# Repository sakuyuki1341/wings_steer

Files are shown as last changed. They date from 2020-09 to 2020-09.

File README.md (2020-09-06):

# wings_steer

"wings_steer" is a system of steering in U.E.C.wings.

# DEMO

No information.(Additional information will come soon.)

# Features

to use Arduino in this system.
Befor we use Renesas, but now we use it to takeover.

# Requirement

No information.(Additional information will come soon.)

# Installation

No information.(Additional information will come soon.)

# Usage

No information.(Additional information will come soon.)

# Note

No informa

# Author

* Sakuyuki
* U.E.C.wings
* y1810678@gmail.com

# License

"wings_steer" is under [MIT license](https://en.wikipedia.org/wiki/MIT_License).

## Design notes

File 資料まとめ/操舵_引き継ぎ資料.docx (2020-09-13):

# 2020 操舵引き継ぎ資料

## 初めに

まず初めに、今回の操舵はワイヤーリンケージではなく、フライ・バイ・ワイヤを用いて作成しています。それを念頭においた上で読んでください。フライ・バイ・ワイヤとはつまりマイコンでサーボモータを制御して、サーボモータで尾翼を駆動する方式のことです。

また、このサーボモータと尾翼の接合方法についてはここでは説明を行えません。理由は筆者がその部分を担当していなかったためです。
ではどうするかですが、その部分は設計に任せてください。サーボモータの仕様を伝えて強度計算が行われたしっかりしたものを作ってもらうと安心です。

## 基本設計について

操舵はアナログスティックを倒すことで、尾翼のサーボモータを駆動させる回路及びプログラムの作成が最終目的となります。

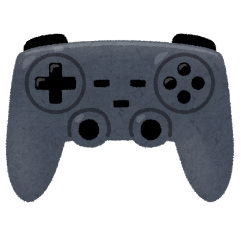
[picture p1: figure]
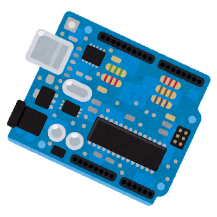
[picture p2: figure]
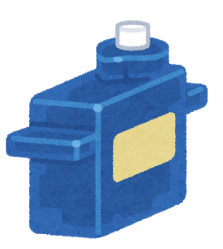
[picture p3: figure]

そこで、必要になるのは「マイコン」「アナログスティック」の３つです。その他に、これらを繋ぎ合わせる基板の設計。マイコンへのプログラミングなどとやらなければいけないことは沢山あります。

## マイコンについて

#### 使用する製品について

使用するマイコンは試用に「Arduino Uno」を。実際に基板に組み込むために「Arduino Nano」を使用します。Nanoは Unoの互換品で機能はそのまま、大きさだけ小さくなったものです。ただ、Nanoは小さく、テストに使用するには不便なため、試し段階であればUnoの使用が推奨されます。

Arduino Nano 販売ページ(秋月電子)(http://akizukidenshi.com/catalog/g/gM-09059/)
Arduino Uno 販売ページ(秋月電子)(http://akizukidenshi.com/catalog/g/gM-07385/)

メーカーは「Arduino Srl」で、上記の製品は秋月電子や千石電商、Amazonなどでも販売されています。また、Amazonでは廉価版、一般にはコピー商品と呼ばれるものが販売されているのでそちらを購入するのも良いでしょう。無論、廉価版でも機能に違いはありません。ただ、保護回路が省略されていたりするので、その点には注意が必要です。

#### 製品の特徴について

- プログラム作成が楽で、プログラム作成のための資料が多くある。
  - Arduino以上に初心者に優しいマイコンは無いため、これを使用している。
  - 入門用の学習書や、学習サイトが豊富なため、自分自身で学べる。

#### 補足

以前はRENESASのマイコンを使用していた。そちらはより軽量でより単価が安く、より高性能となっています。しかしながら使用するには一定以上の高度な技術と知識が必要となるので推奨しません。RENESAS以外にもpicマイコンという安価なマイコンがあるため、使用するにはそちらを選択してください。なぜなら、RENESASに比べてpicは多少資料が多いため、いざとなったらインターネットで検索をすれば使用方法などの知識を得やすいからです。

もし、Arduinoから別のマイコンへと乗り換えるのであれば引継ぎはしっかりと行ってください。

## アナログスティックについて

アナログスティックに関しては、本資料を読むよりも先に該当のデータシートを見ることを強く推奨します。また、本資料にはデータシートには書いていない注意事項を記載しているので、その点については本資料で確認してほしいです。

#### 使用する製品について

使用しているアナログスティックは「SainSmart」の「JoyStick Module」で、秋月電子で販売されています。

JoyStick Module 販売ページ(秋月電子)(http://akizukidenshi.com/catalog/g/gM-08763/)

#### 製品の特徴について

- 中央部と外縁部のデッドゾーンが大きく、繊細な動きをしづらい。

#### 補足

特徴の項目からも分かるように、この使用しているアナログスティックは性能が低いです。そのため、実際に機体に搭載する際はより高機能なアナログスティックを購入、使用する必要があります。また、アナログスティックを変更した場合は、それに応じてマイコン側のプログラムも適宜変更してください。

## サーボモータについて

サーボモータはアナログスティックと異なり、データシートが複雑で読むのが辛いと思うので、ここではできるだけ噛み砕いて書いていきたいと思います。
　ただ、噛み砕くということは細部について触れないということなので、そこについてはデータシートや、公式が配布している資料を読んでください。

#### 使用する製品について

使用するサーボモータは「近藤科学」の「KRS-4031HV ICS」で、通販などで販売されています。(昔はツクモロボット王国という店で店頭販売されてたけど、最近はどこで買えるのかわからないです。申し訳ないです。)

近藤科学 公式販売ページ(https://kondo-robot.com/product/krs-4031hv-ics)

#### 製品の特徴について

- 「ICS3.5」という近藤科学独自のシリアル通信規格での制御が可能なため、信頼性が高い。 無論、pwm制御も対応しており、そちらを利用して制御することもできる。
- 駆動電圧が9-12Vで、リポバッテリーを直付けで駆動できる。
- サーボホーンは付属していないため、この製品に対応したものを購入する必要がある。 例：近藤科学 サーボホーン公式販売ページ(hhttps://kondo-robot.com/product/allowhighthorn)

#### 補足

この他にもサーボモータは様々な企業が販売しているため、一番使いやすいサーボモータを探してみるのも良いでしょう。ただ、その際はトルクや駆動電圧には細心の注意を払う必要があります。また、近藤科学のサーボモータにも色々種類があるので、尾翼の駆動のために更にトルクが必要になった場合などは、トルクの大きいものに買い替えてください。

また、サーボモータを駆動するためのICS3.5という通信規格ですが、当然ではありますが、Arduinoでポンと出力することはできません。そのため、適切な回路設計とソフトウェア設計が必要です。
　一応、公式側からArduino用のライブラリが公開されているのでそれを利用してもいいでしょう。(筆者は参考サイト様：リンク(https://qiita.com/kedtn/items/7174f5112d99f12ce0e7))を見ながら自分で組んだので、どのようにライブラリを利用するのか分からないので解説はできません。)
　他にも公式から、ICS3.5用のモジュールが購入できるみたいです。自分で回路を設計できない場合はそれを利用するのが一番安全です。
　あと、ソフトウェア側の解説でも記述するのですが、Arduinoのソフトウェアシリアル機能は115200bpsに対応していないので、ArduinoでICS3.5を使用するならハードウェアシリアルを使用してください。

## 操舵基板(回路)について

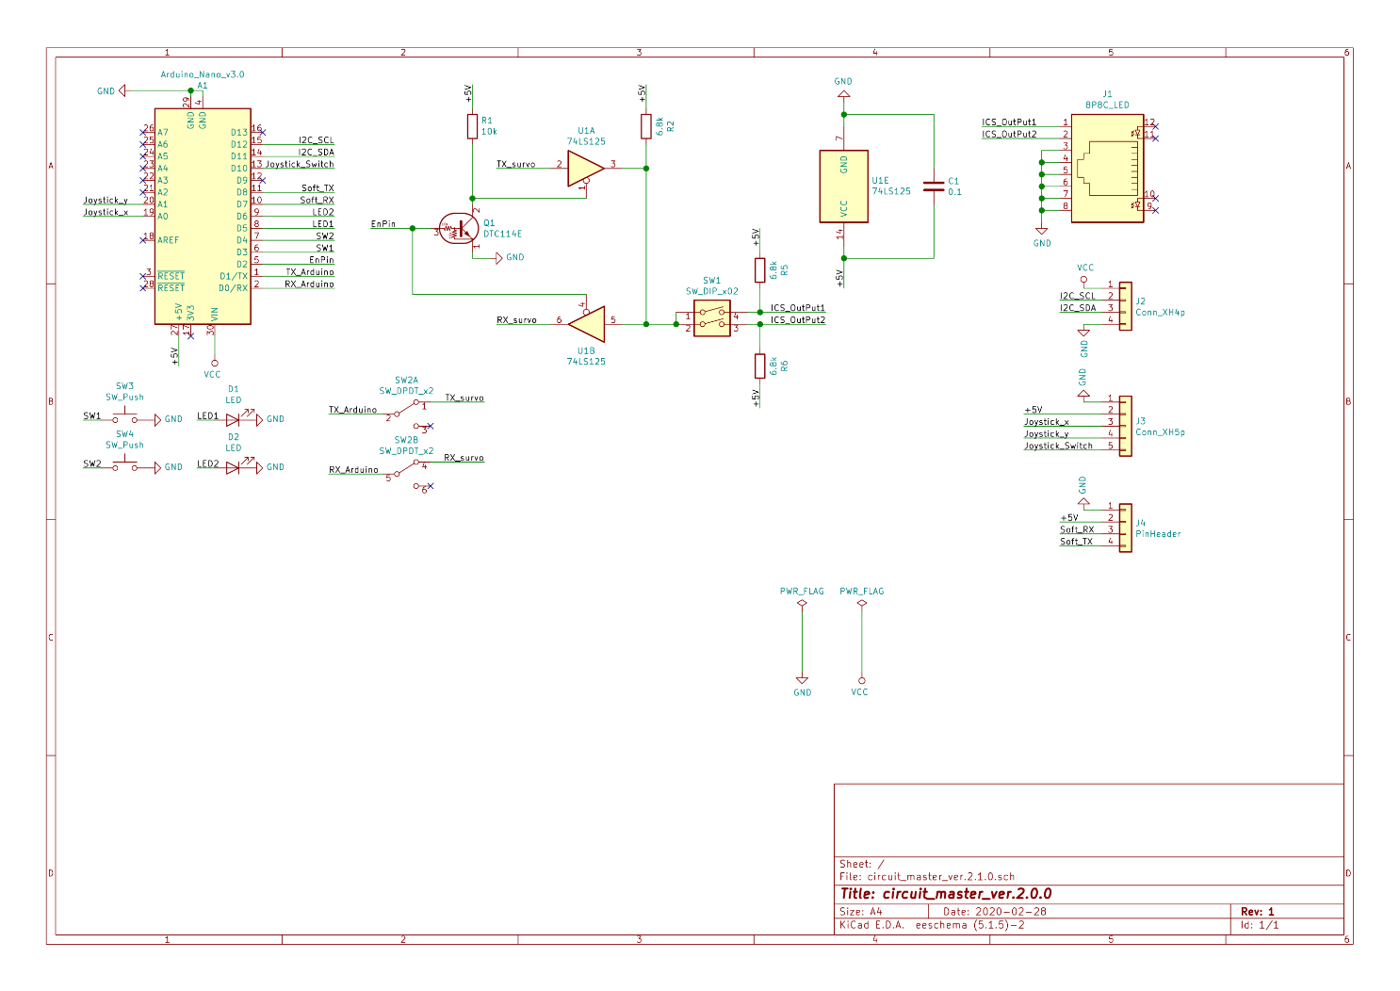
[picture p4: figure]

操舵基板というのは、マイコンとその他の電子部品を詰め込んだ基板のことを指します。下の画像が現在使用している操舵基板の回路図です。

#### 操舵基板の役割について

操舵基板は操舵の電気的部分に関するほぼ全てを担います。そのためこの基板と「メイン基板」「尾翼側にあるサーボモータ」「コックピットのアナログスティック」を接続する必要があります。

また、情報処理もこの基板内で行いたいので、Arduino本体もこの基板に搭載することとなります。

それ以外にも、Arduinoの動作状況を確認するためのLEDや、Arduinoのデバッグを行うためのシリアル通信用のポート、Arduinoを操作するためのスイッチも搭載しています。

#### 設計について

回路図の設計はKiCadを用いて行いました。なので、回路図や基板を見る場合はそれを利用してください。自身で新規に基板や回路を作成する場合は、KiCadを用いても良いですし、Eagleを用いても良いでしょう。

なお、回路の設計には「KiCad Basics」と「自作基板への道」という参考資料を活用しました。この２つは引き継ぎの資料に同梱してあるので活用してください。

#### 回路について

回路図とパーツについては、渡したデータを参照すれば、どれがどれに対応しているか分かるかと思います。

#### 設計時の注意点

- サーボモータはArduinoのハードウェアシリアルで制御する必要があります。そのため、UARTをICS3.5へ変換する回路はハードウェアシリアルの出力のピンへと接続しましょう。
- ICS3.5へ変換する回路を接続したままだと、Arduinoへの書き込みができません。そのため、ここの接続を切るためのスイッチが必要です。上記回路図上だとSW2に該当します。
- ハードウェアシリアルはサーボモータとの通信に専用されます。そのためデバッグ用にソフトウェアシリアルを用いてArduinoと通信するためのピンを用意しましょう。 恐らくですが、Arduino Nanoはソフトウェアシリアルに使用できるピンに制限はないと思われます。D2~D12かに割り当てれば問題ないはずです。
- インジケータ用のLEDと、スイッチは用意しておきましょう。忘れるソフトウェア設計面でも支障がでます。

#### 備考(LANコネクタについて )

今回の基板ではLANコネクタを搭載することにしています。これは操舵基板と尾翼のサーボモータを接続するためのものです。つまり、操舵基板とサーボモータはLANケーブルで接続するということです。

LANケーブルで接続するのは何点かメリットがあります。

1. 接続、切断がアタッチメントを用いることで容易に可能であること。
2. 挿し間違いが極めて発生しづらい。
3. ケーブルの代替品が簡単に用意できる。

もちろん、通常のケーブルと比べて重量の増加というデメリットも発生するので、安定重視ならLANケーブルを。効率重視なら専用ケーブルを選択するのが良いでしょう。

#### 備考(各要素との接続端子について)

アナログスティックと操舵基板間

XH規格の圧着端子をつけた銅線を用いて接続します。その際には「アナログスティック_x軸」「アナログスティック_y軸」「アナログスティック_スイッチ」「5V」「GND」の5ピン必要となるため、対応したものを選びましょう。
　ケーブルは一般的な安価な銅線で問題ないでしょう。

サーボモータと操舵基板間

前述の通り、LANケーブルを用いて接続します。とは言え、LANケーブルとサーボモータを直接繋ぐことはできないので、LANケーブルをピンヘッダへ変換する基板を尾翼周辺に配置して、変換をした後にサーボモータへ接続することとなります。また、その変換基板にサーボモータ用電源も接続し、サーボモータはその変換基板とのみ接続できるようにしました。
　操舵基板からは「GND」「サーボモータ１の通信線」「サーボモータ２の通信線」の3種類。LANピンヘッダ変換基板では、サーボモータそれぞれに「GND」「通信線」「VCC(12V)」の３つ。操舵基板との「GND」「サーボモータの通信線」×２(ただしLANを用いる)。サーボモータ電源(リポバッテリー)との「GND」「VCC(12V)」の２つ(ピンヘッダ)を用意します。

## 操舵基板(基板)について

前項では主に回路について記述しました。本項では基板の設計について書いていきます。基板の設計の画像はレイヤーでごちゃごちゃしているので載せません。KiCadを使って自身で実際に確認してみてください。

#### 設計について

基板の設計ですが、回路の「設計について」の項目と内容は同じのため省略します。

#### 発注について

発注はFusionPCBが恐らく一番安価だと思います。品質も問題ないので活用しましょう。

一応、学内のものつくりセンターに基板作成機がありますが、使用方法が面倒な上、品質もお世辞にも良いとは言えないので、おすすめしません。もしどうしても使用したいならば、事前にものつくりセンターに登録を行い、使用方法を確認しておきましょう。
　使用方法はwikiに記述されているはずです。(なかったら申し訳ないです。)

#### 設計及び発注時の注意点

- 一つ一つの電子素子(トランジスタとか)のデータシートをみて、ピン配置について確認しましょう。稀に予定していたものとズレていることがあります。また、回路図とも照らし合わせて考え通りに割り当てがなされているかを確認しましょう。
- 発注する際は必ず発注先のサイトでガーバーデータの生成方法を確かめましょう。そこに一通り生成方法が記述されているので、生成で手間取ることもなく進められるはずです。
- 誤発注を避けるため、ガーバーデータを提出したら、確認ページを見ましょう。そうすればきっと誤発注が防げる…はず。

## Arduinoに書き込むプログラムについて

この項ではArduinoに書き込むプログラムについて解説します。恐らく長くなるので心して読んでください。なお、基本的なArduinoのプログラミングはこなしたものとして説明を行います。そのため、Arduinoってなんぞやって人は、事前に「Arduino 入門」とかで検索をして、少なくともLEDをボタンで光らせる程度はできるようになっておいてください。

#### ソースコードのダウンロードについて

Arduinoへ書き込むソースコードは筆者のgithub上→(リンク：https://github.com/sakuyuki1341/wings_steer)にあります。また、ソースコードだけでなく、本資料や回路図などなどもあるので確認してみてください。

本番用のプログラムは「master」というディレクトリに入っているので、そこから最新のバージョンをダウンロードしてください。

#### 概要

このプログラムは6つのファイルがあります。それぞれ以下のような役割を持ちます。

1. steering_master_ver.1.0.ino：setup関数やloop関数の存在するメイン部。
2. servo_ver.1.0.ino：サーボモータの駆動に関する関数群
3. analog_stick_ver.1.0.ino：アナログスティックに関する関数群
4. command_line_ver.1.0.ino：コマンドラインに関する関数群
5. memory_ver.1.0.ino：メモリの読み書きに関する関数群
6. subs_ver.1.0.h ：構造体や変数、関数の宣言をまとめたもの。

これらそれぞれについて順に解説をしていきます。

#### subs_ver.1.0.hについて

このファイルでは、他のファイルが使う変数、定数、関数、構造体の宣言を行っています。

#### Steering_master_ver.1.0.inoについて

まずは各種パラメータの初期値を設定する。ここの値は自由に設定して構わないです。

次にsetup関数だが、ここにある関数init_stick, init_cmd, init_servo, init_memoryはsubs_ver.1.0.hにて宣言されている。定義は別ファイルにあります。

Arduinoが起動されてループすることになるloop関数だが、ここではサーボの駆動、デバッグモードへの移行判定、スティックの押し込み判定を行っています。また、デバッグモードへ移行した場合は、ロードスイッチが押されるかの判定を行います。

スティックの押し込み、デバッグモード、パラメータロードスイッチの詳細については、ソースコードと同階層にある「read_me.txt」を読んでください。

#### servo_ver.1.0.inoについて

基本的には参考サイトを基にコードを作成しています。特に、サーボモータへ送るコマンドの部分に関しては、完全にコピーしているだけです。（参考サイト様：https://qiita.com/kedtn/items/7174f5112d99f12ce0e7）

私が作成した部分について解説します。

関数move_servoではスティックの情報を取得。計算をし、そのデータを送信するだけとなっています。

関数calc_angleではスティックのアナログ値などから、サーボモータへ送る値を計算します。細かい計算式については、ソースコードと同階層にある「calc_angleについて.txt」を読んでください。
　calc_angleには計算式以外に気をつけなければいけないことがあります。計算する際の値が大きくなり、計算順序によっては値がオーバーフローします。そのため、calc_angleの計算式を変更する場合はそこに注意してください。また、挙動が変化した場合は、デバック用とコメントを残したところを使用して、送信値が正常かどうか判断してください。異常の場合は、()をつけて計算順を変化させるか、型を変えてオーバーフローしない型の使用をしてください。

関数ics_set_idはサーボモータへIDの書き込みをするものです。

注意
サーボモータへのID書き込み時は注意が必要です。接続しているサーボモータ全てへIDの書き込みがされるからです。そのため、この関数を使用する際は、サーボモータへの接続を切断してください。物理的に切断してもいいですが、基板上のServo selectorスイッチを使用して切断してもOKです。

現状ある関数は少ないですが、必要に応じてコマンドを増やしてください。コマンドはICS3.5のソフトウェアマニュアルと、参考サイトを使用すれば作成できるはずです。

#### analog_stick_ver.1.0.inoについて

ここでは、スティックのスイッチがつながっているピンの初期化用のinit_stick。そして、スティックの各種状態値を取得するstick_stateのみ記述しています。

#### command_line_ver.1.0.inoについて

コマンドラインは、デバッグモード中にArduinoと対話形式でやり取りするためのものです。

システム自体は単純です。cmdline関数は、まずシリアル通信の受信をおこない、コマンドの取得をします。その後に、そのコマンドに対応する関数が存在するかを検索します。存在すればその関数を実行します。

コマンドを追加したい場合は、上部の「COMMAND_TOTAL_NUM」を適宜増やし、コマンドテーブルにコマンドを追加。コマンド関数を作成し、コマンドが実行された際の処理内容を関数内に記述してください。

#### memory_ver.1.0.inoについて

Arduino内部には不揮発性メモリがあり、EEPROMの各種関数を使用して書き込みと読み込みができるようになっています。不揮発性なので電源を落としても値を保持できるので、いちいちArduinoへプログラムを書き込むことなくパラメータの変更をさせることができます。

関数save_parametersでは各種パラメータを保存することが、関数load_parametersでは各種パラメータをROMから読み取ることができます。

#### 既知のバグ

- command_line_ver.1.0.inoのhelp関数ですが、現在はコマンドリストを開く機能は搭載されていません。
- command_line_ver.1.0.inoには、現在centerPS_x, centerPS_y, speed, stretchを変更する関数は搭載されていません。
- command_line_ver.1.0.inoには、現在stretch, speedをサーボモータへ書き込む関数は搭載されていません。

## 使用方法について

本当は最初に書くべきでしたが、最後になってしまい申し訳ありません。基本的な使用方法は順に。副次的な機能は箇条書きで記述します。

1. 操舵基板とスティック。操舵基板とメイン基板。操舵基板と尾翼の変換基盤。尾翼の変換基盤とサーボモータ。この4つを接続します。(この他にも接続するものがあったら適宜接続を)
2. すると、メイン基板からの給電でArduinoが起動するので、操作ができるようになります。
  - パラメータを読み込む場合は、デバッグモード移行スイッチ(SW4)を押してデバッグモードに移行します。その後、パラメータ読み込みスイッチ(SW3)を押して読み込みを行います。
  - スティックの中央値を変更したい場合はスティックを押し込みます。押し込んだら、スティックを中央に戻すか、1秒経過すると、押し込んだ場所を中央としてサーボモータを操作することができるようになります。
  - PCとシリアル通信する場合は、シリアル変換基板とPCを、シリアル変換基板と操舵基板を接続して、デバッグモードをONしてください。そうすることで、コマンドラインが有効化されてコマンドによる操作ができます。 なお、PCとArduinoでシリアル通信する場合ですが、PCのシリアル通信のターミナルはArduinoのIDEのシリアルモニタを使用してください。 COMポートをシリアル変換基板のものに設定してシリアルモニタを起動すればOKです。

#### 備考(注意点など)

まず、注意して欲しいのが、サーボモータへIDを書き込むときは、書き込みたいサーボモータのみ接続するようにしてください。両方接続したままだと、両方へ書き込みが行われてしまいます。

次はServo↔PCスライドスイッチですが、コレがPC側になっているとPCからArduinoへ書き込みができます。Servo側の場合、サーボモータへ通信されます。

他には混線や、故障の原因になる可能性がある操作は無いですが、製品では無いので注意してしすぎることはないので、変な使用方法をしないようにしてください。

#### トラブルシューティング(既知のバグの対処法)

- Arduinoへ書き込みができない。
  - Servo↔PCスライドスイッチがServo側になっていませんか？PC側にしないと書き込みは行えません。
- サーボモータへ通信されない。
  - Servo↔PCスライドスイッチがPC側になっていませんか？Servo側にしないと通信はされません。
  - Servo selectorがoffになっていませんか？onにしないと通信はされません。
  - サーボモータの認識しているIDと、送信しているIDに相違はありませんか？分からなければ一度IDの書き込みをしましょう。

## 読んでる人がやらなくてはならないこと

コレを読んでる人はいかに書いてあることをとりあえずやらなければいけません。(私がやり残したことですが…)

- 基板を新たに作成する。私が作ったのはデバッグのために圧着端子や、LANソケットが全てピンソケットになっています。これをちゃんと圧着のものとLANソケットになっているものにしてください。
- 尾翼の変換基板を設計・作成する。LANからサーボモータが接続できるようなピンヘッダへ変換するものです。
- 操舵基板、スティックなど諸々を固定する方法の考案。そして機体に固定できるようにしてください。

以下はできればですが

- ソフトウェアを読んで、足りない機能の補完。
- この資料の足りない箇所の追記。

これらをやってくれれば、操舵係として失敗することは無いはずです。

## 最後に

上記のことと、実際のソースコード。回路図などを見れば大体は分かるはずです。(中には書き漏れがあるかもですが…)
もし、これらでも分からなくて「詰まった」と思ったら筆者の私に連絡してください。相当忙しくなけれ手助けができると思うので。

以下筆者について
役職など：20代代表兼電装
mail1：y1810678@edu.cc.uec.ac.jp
mail2：forestry.for@gmail.com

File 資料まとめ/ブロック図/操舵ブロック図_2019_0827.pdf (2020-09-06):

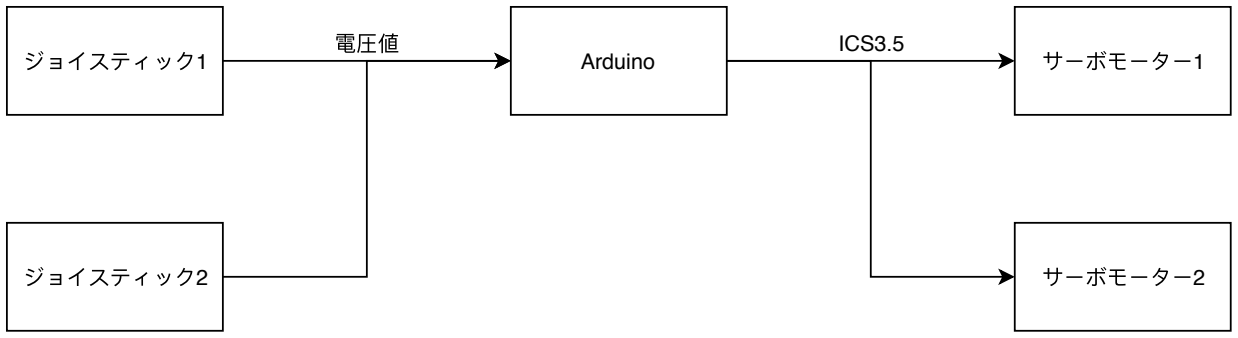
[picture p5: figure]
ジョイスティック1; Arduino; ジョイスティック2; 電圧値; サーボモーター1; サーボモーター2; ICS3.5

# 補⾜説明

ICS3.5とは

近藤科学のサーボモーター特有の
通信規格だが、普段使⽤する通信
規格のUARTを使⽤しても通信可
能である。

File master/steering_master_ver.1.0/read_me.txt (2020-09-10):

steering_master_ver.1.0について
――――――――――――――――――――――――――――――――――――――
基本的な機能は全て搭載したバージョン。

使用方法
――――――――――――――――――――――――――――
まず最初に、このプログラムは2つの動作モードがある。
　１．通常モード
　２．デバッグモード

　通常モードについて
――――――――――――――――――――――――――――
　通常モードは、パイロットが実際に搭乗して使う際を想定して作成してある。
　そのため、余計な処理は全て行わないようにし、操作系統はスティックで完結するようになっている。
　通常モード時は以下のような操作が可能となっている。
　　１．スティックを倒すことにより、サーボを駆動する。
　　２．スティックの押し込みにより、動作の中央値を移動する。
　１については特に記述する必要はないだろう。
　２についてだが、こんな場面を想像してほしい。パイロットは高度を維持するために、
　スティックの角度を一定に保たなくてはならない。しかし、それと同時にペダルを漕ぎ続けるのは至難の業だ。
　そういうときに、スティックが傾いている状態を維持できれば非常に良いだろう。
　その機能をどうやって実現するかというと、スティックを傾けた状態で押し込むと、そこを中央値と認識するようにすれば良いだろう。
　２はそのような機能のことを指している。

　以上が通常モード時の操作だ。

　デバッグモードモードについて
――――――――――――――――――――――――――――
　デバッグモードは通常モード時に基板上のデバッグモード移行用のスイッチを押せば有効化される。
　有効化されると基板上のデバッグモードを示すLEDが点灯する。
　デバッグモード時は以下のような操作が可能となっている。
　　１．通常モード時に行える操作全て。
　　２．ソフトウェアシリアル通信を介したコマンドラインによる制御
　　３．パラメータロードボタンの使用。
　１はデバッグモード時にも通常モード使用時と同じように動作を確認したいため搭載。
　２は細かな設定や、状態の確認。パラメータをサーボモータへ書き込むために使用。
　３はプラットフォーム上などのパソコンをつかってコマンドライン制御できない際に使用する。長押しした場合に読み込みを行う。
　なお、デバッグモードから退出するにはデバッグモード移行用のスイッチをもう一度押せばいい。

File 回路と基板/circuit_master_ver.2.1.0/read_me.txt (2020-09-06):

ver.2.0.0での変更点
・シリアル通信ピンを11, 12からハードウェアシリアル用のピンへ変更
・抵抗入りトランジスタの足が間違っていたので修正
・DIPスイッチを2個に変更
・PCとサーボの通信切り替え用スイッチの搭載

2020/3/28
ver.2.1.0での変更点
・アナログスティックとArduino間の回路に間違いが会ったため修正
・PC↔サーボの切り替えスイッチを一つに変更
・汎用ハードウェアスイッチ×2, 汎用ハードウェアLED×2の追加
・ソフトウェアシリアル用のピンヘッダ追加

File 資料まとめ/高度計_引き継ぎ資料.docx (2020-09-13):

# 2020 高度計引き継ぎ資料

一応資料としては残していますが、これといって引き継げる事は無いため、高度計の作成についていくつかのアドバイスのようなのものになりますが、ご勘弁を。

まず、高度計とは、機体が地上からどれくらいの高さにあるかを判別するための計器です。計測方法は、高度計のモジュールから超音波を送信し、受信するまでの時間で距離の測定を行うこととなります。

高度計の根幹となるモジュールですが、「MB1260-000」というものを使用します。(MB1360でも代用可)
　このモジュールの利点は

- 非常に小型
- 中距離(10mほど)まで測定可能
- 仕様が完結で、簡単に使用できる

などあります。

19代までは自作で高度計を作成していましたが、システムも回路も複雑で、恐らく使用するのが難しいと判断し、こちらへと切り替えることにしました。

使用方法は簡単にいうと、このセンサへ電力を送り、このセンサの特定のピンから出力される電圧値をアナログリードする。という手順となります。なので、Arduinoの練習の一環として高度計を作成するのがいいでしょう。

なお、高度計をコックピットへどのように取り付けるかはおまかせします。

購入ですが、このモジュールは需要が少ないのか店頭販売はされていないため、オンラインショップで購入することになります。販売サイトは「marustu」と「digi-key」の２サイトです。恐らくどちらで買っても品質に問題は無いはずです。

最後になりましたが、このMB1260の販売ページを以下へ書き記しておきます。

MB1260-000販売ページ(marutsu)(https://www.marutsu.co.jp/pc/i/29658722/)
MB1260-000販売ページ(digi-key)(https://www.digikey.jp/product-detail/ja/maxbotix-inc/MB1260-000/1863-1032-ND/7896804)

資料製作者
20代表兼電装班 山田
mail1：y1810678@edu.cc.uec.ac.jp
mail2：forestry.for@gmail.com

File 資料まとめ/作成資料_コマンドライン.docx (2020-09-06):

# 作成資料

## コマンドラインについて

コマンドライン自体は「serial_test_08」にて正確なやり取りに成功した。

なぜここまでテストに問題が生じたかというのを以下に書いていこうと思う。

まず最初にして最大の難関は、文字列のやり取りになると思う。

シリアル通信でarduinoとPC間で文字列を送受信するコマンドラインだが、「serial_test_05」辺りを見てもらえると分かるが、「Serial.read()」を用いて一文字ずつ読み取りを行おうとしていた。

ただ、これをした場合、原因は不明だが正常に処理することが結果としてできなかった。

そのため、基本的には「Serial.readString()」もしくは「Serial.readStringUntil()」を用いることを推奨する。

今回の文字列のやり取りでは「Serial.readStringUntil()」使用しているが、理由はarduinoのシリアルモニタを使用し文字列を送信すると、必ず文字列の最後に「\n」という改行文字が送られるため、これを起点にコマンドの取得をするのがシンプルに記述することができたからである。

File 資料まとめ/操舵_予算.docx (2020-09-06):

# 操舵必要物品一覧

# Arduino_nano

参考URL: http://akizukidenshi.com/catalog/g/gM-09059/

必要金額: \ 2780 (税込み)

# ジョイスティック (2コ)

参考URL: http://akizukidenshi.com/catalog/g/gM-06807/

必要金額: \ 980 × 2 (税込み)

# サーボモータ (2コ)

参考URL: https://kondo-robot.com/product/krs-4031hv-ics

https://www.marutsu.co.jp/pc/i/167124/

必要金額: \ 7150 × 2 (税込み)

備考: 現在までこのサーボを使用してきたけど、

もうちょいトルクのあるサーボを使用したほうが安全ではある

例: https://kondo-robot.com/product/krs-4032hv-ics

https://kondo-robot.com/product/krs-4033hv-ics

ただし、トルクを上げると1つあたり1万値上がりするからどうしようか？

# 基板発注費

発注先サイトは未定

P板.com (https://www.p-ban.com/)で見積もった所

必要金額: \ 20200 (税込み)

# その他

ジャンパーワイヤ / 機体配線用のワイヤ / etc…

必要金額: \ 3000

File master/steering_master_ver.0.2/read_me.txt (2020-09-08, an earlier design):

steering_master_ver.0.2について
――――――――――――――――――――――――――――――――――――――
　ver.0.2では新規作成した基板上で各種基幹機能が正常に動作するかを検証した。
　ここで確認したのは「アナログスティック」「コマンドライン」「サーボモータ」の三種の機能と、
それらの連携についてだ。また、メモリを使用した機能は確認していない。

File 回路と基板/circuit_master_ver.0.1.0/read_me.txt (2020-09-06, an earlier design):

このデータは
　　KiCad (5.1.5)
で作成しました。
ライブラリも既存のものしか使用していないので、
閲覧編集するのに必要なのは上記のソフトさえあれば十分です。

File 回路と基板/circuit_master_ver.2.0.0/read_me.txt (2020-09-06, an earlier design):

ver.2.0.0での変更点
・シリアル通信ピンを11, 12からハードウェアシリアル用のピンへ変更
・抵抗入りトランジスタの足が間違っていたので修正
・DIPスイッチを2個に変更
・PCとサーボの通信切り替え用スイッチの搭載

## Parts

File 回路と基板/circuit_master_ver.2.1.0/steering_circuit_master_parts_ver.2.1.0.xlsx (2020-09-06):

部品番号 |  | 品目/名称品目 | 型式/品番型式 | 定格 | メーカー | パッケージ | 数量 | 購入先 | 価額 | 備考
プレフィックス | サフィックス
U | 1 | 3ステートバッファ | SN74HC125N |  | Texas Instruments |  | 1 | 秋月電子 | ¥30
U | 2
Q | 1 | 抵抗入りトランジスタ | DTC114EL |  | ユニソニック |  | 1 | 秋月電子 | ¥10
R | 1 | カーボン抵抗 |  | 10kΩ |  |  | 1 | 秋月電子 | ¥100 | 100個入り / 1/6W以上
R | 2,5,6 | カーボン抵抗 |  | 6.8kΩ |  |  | 3 | 秋月電子 | ¥100 | 100個入り / 1/6W以上
C | 1 | セラミックコンデンサ |  | 0.1μF |  |  | 1 | 秋月電子 | ¥15
J | 1 | LANコネクタ | RJLD260TC1 |  | TAIMAG | RJ-45 | 1 | 秋月電子 | ¥200
J | 2 | XHコネクタ ベース付きポスト | B4B-XH-A |  | JST | XH | 1 | 秋月電子 | ¥10
J | 3 | XHコネクタ ベース付きポスト | B5B-XH-A |  | JST | XH | 1 | 秋月電子 | ¥10
J | 4 | ピンヘッダ |  | 1×40 |  |  | 1 | 秋月電子 | ¥35 | L字型ではない / 分割して使用
S | 1 | DIPスイッチ 2P |  |  | ECE | EDS | 2 | 秋月電子 | ¥50
S | 2 | 超小型スライドスイッチ | IS-2235 | 2回路2接点 |  |  | 1 | 秋月電子 | ¥100
S | 3,4 | タクトスイッチ |  |  |  |  | 2 | 秋月電子 | ¥10 | 別色で用意する
D | 1,2 | 抵抗内蔵5mmLED |  | 5V用 |  |  | 2 | 秋月電子 | ¥15 | 別色で用意する
A | 1 | Arduino Nano |  |  | Aruduino Srl |  | 1 | 秋月電子 | ¥2780
 |  | 超小型USBシリアル変換モジュール | FT234 |  | 秋月電子通商 |  | 1 | 秋月電子 | ¥600 | デバッグ用
 |  | 分割ピンソケット |  |  |  |  |  |  |  | Arduino用
 |  | IC用分割ピンソケット |  |  |  |  |  |  |  | 3ステートバッファ用

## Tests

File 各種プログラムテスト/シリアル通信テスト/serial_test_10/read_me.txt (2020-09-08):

=======
* 説明 *
=======
ソフトウェアシリアル通信を用いた、コマンドラインの実装実験1。
今回は新規作成した基板がソフトウェアシリアルの実行をできるかを調査する。
よってコマンドライン自体の動作を確認するものではない。

=======
* 結果 *
=======
成功。基板に以上は確認されなかった。
また、いくつか新たに判明したことがある。

=======
* 考察 *
=======
１．ソフトウェアシリアルのボートレートだが、これは57600bpsが最適となる。
　　公式で確認したものでないため、間違っている可能性もあるが、ソフトウェアシリアルを使用している際は、
　　ソフトウェアシリアル側にCPUのリソースの100%使用されるため、他の処理が行えない。
　　そのため、できるだけ送受信の時間を減らさなければならない。
　　ただ、ソフトウェアシリアルは115200bpsには対応できないため、その一段階下の57600bpsを選択するのが良い。
２．teratermはシリアル通信する上で行単位送信ができなかったため、通信はarduinoのIDEを用いて行うと良い。

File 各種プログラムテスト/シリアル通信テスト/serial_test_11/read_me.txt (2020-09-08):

=======
* 説明 *
=======
ソフトウェアシリアル通信を用いた、コマンドラインの実装実験2。
今回はソフトウェアシリアルを用いてコマンドラインが実行できるかを確認する。

=======
* 結果 *
=======

=======
* 考察 *
=======

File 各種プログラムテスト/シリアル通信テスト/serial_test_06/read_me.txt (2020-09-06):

成功したビルド

更新: コマンドを正常に処理することが可能となった
実装予定: コマンドラインとしての概形作成

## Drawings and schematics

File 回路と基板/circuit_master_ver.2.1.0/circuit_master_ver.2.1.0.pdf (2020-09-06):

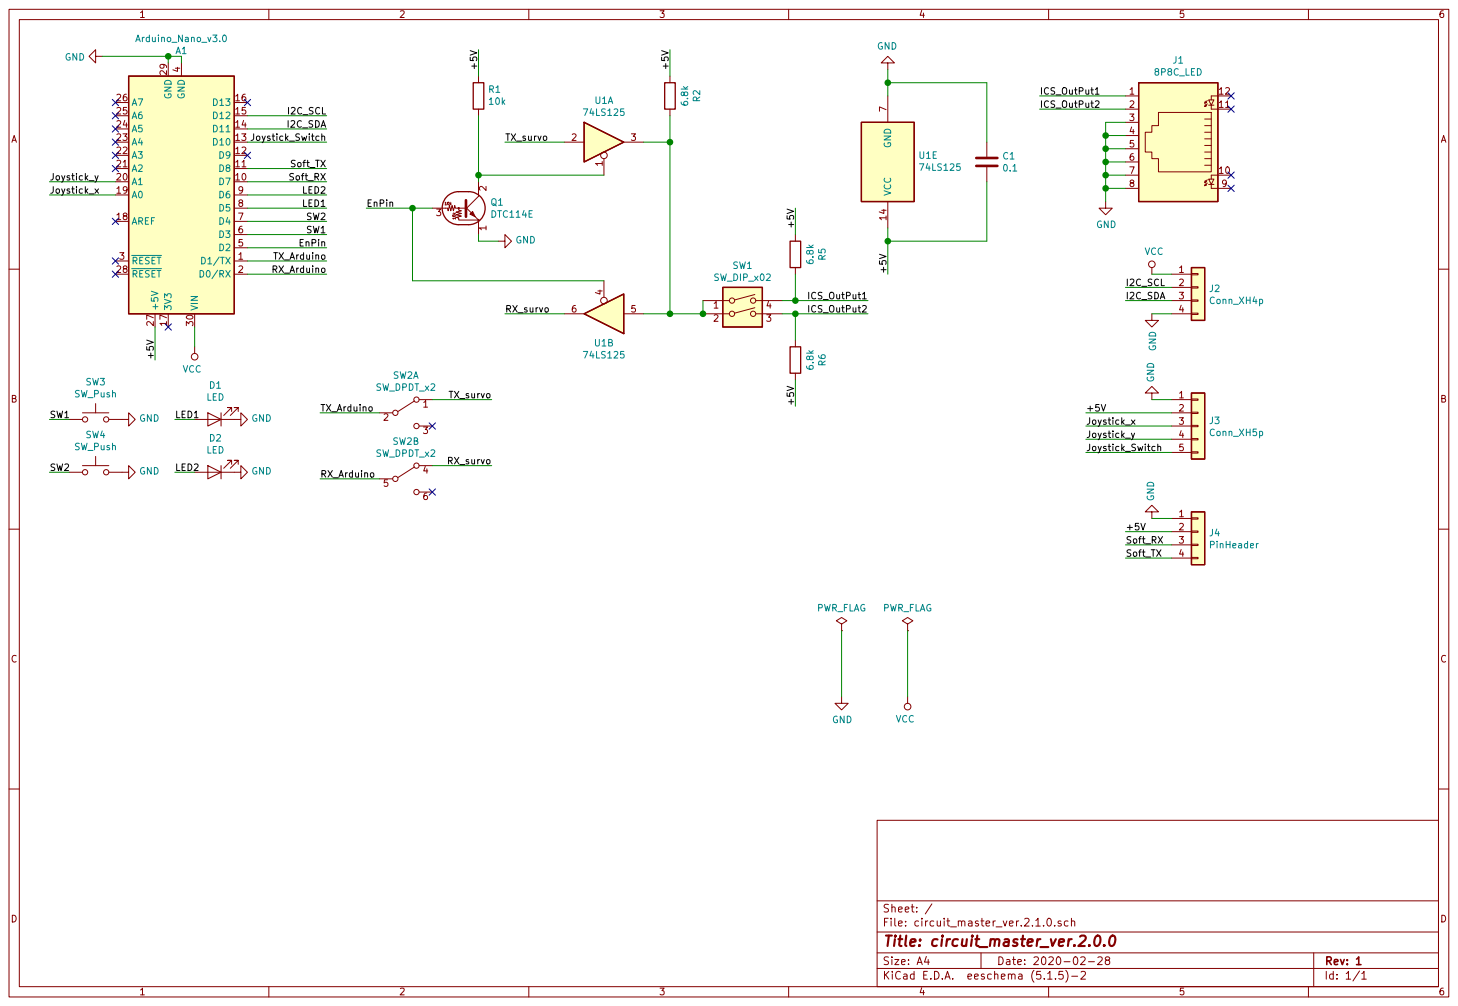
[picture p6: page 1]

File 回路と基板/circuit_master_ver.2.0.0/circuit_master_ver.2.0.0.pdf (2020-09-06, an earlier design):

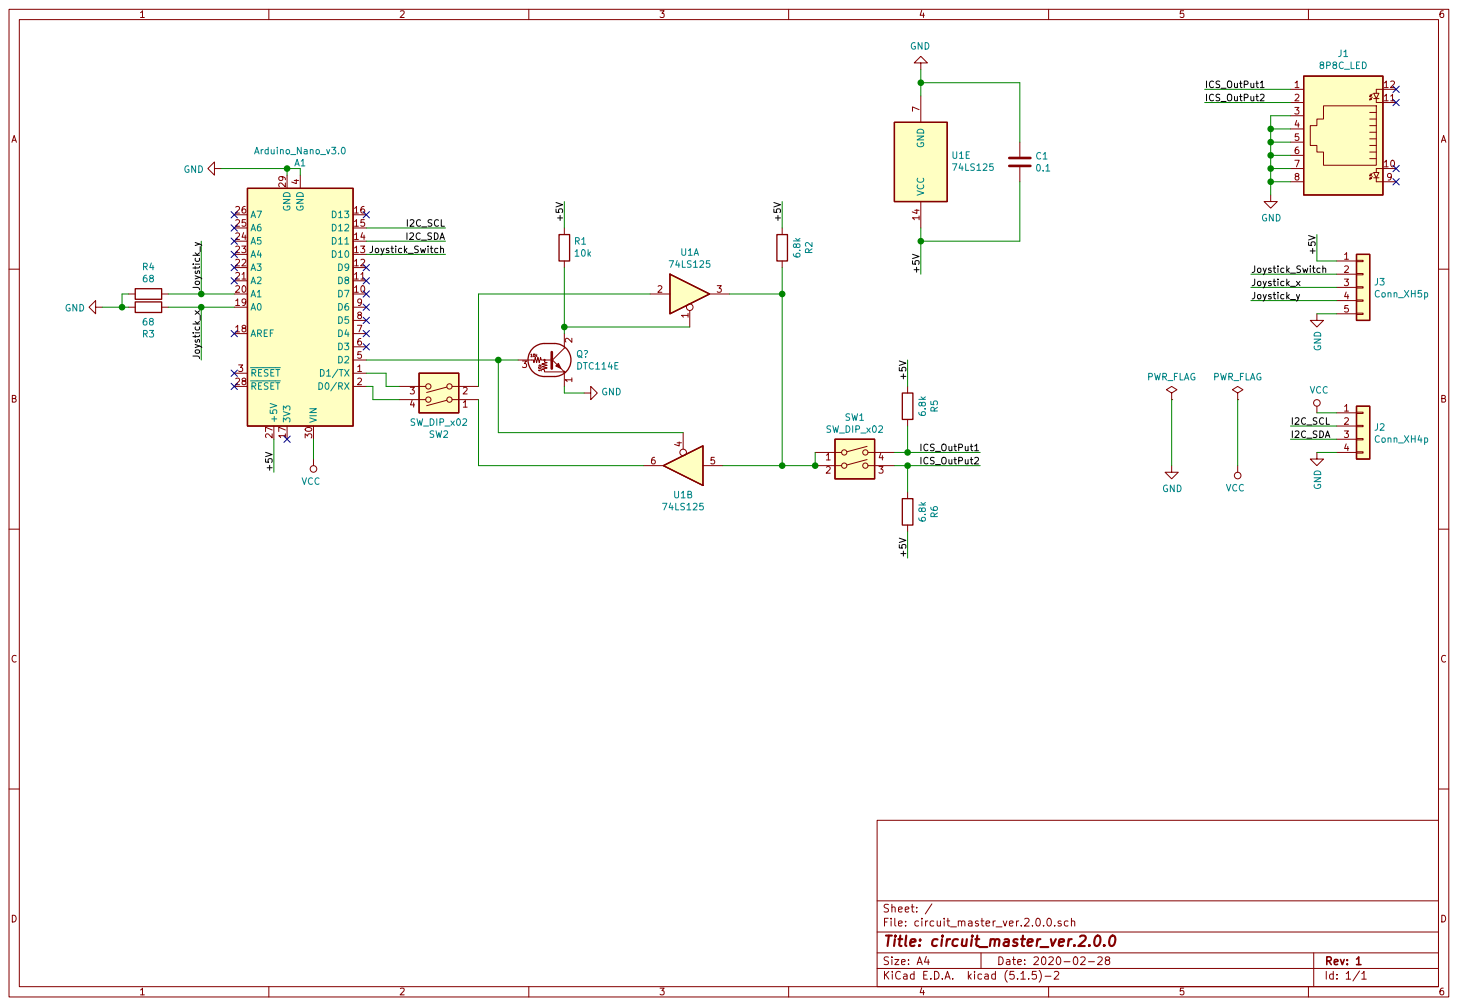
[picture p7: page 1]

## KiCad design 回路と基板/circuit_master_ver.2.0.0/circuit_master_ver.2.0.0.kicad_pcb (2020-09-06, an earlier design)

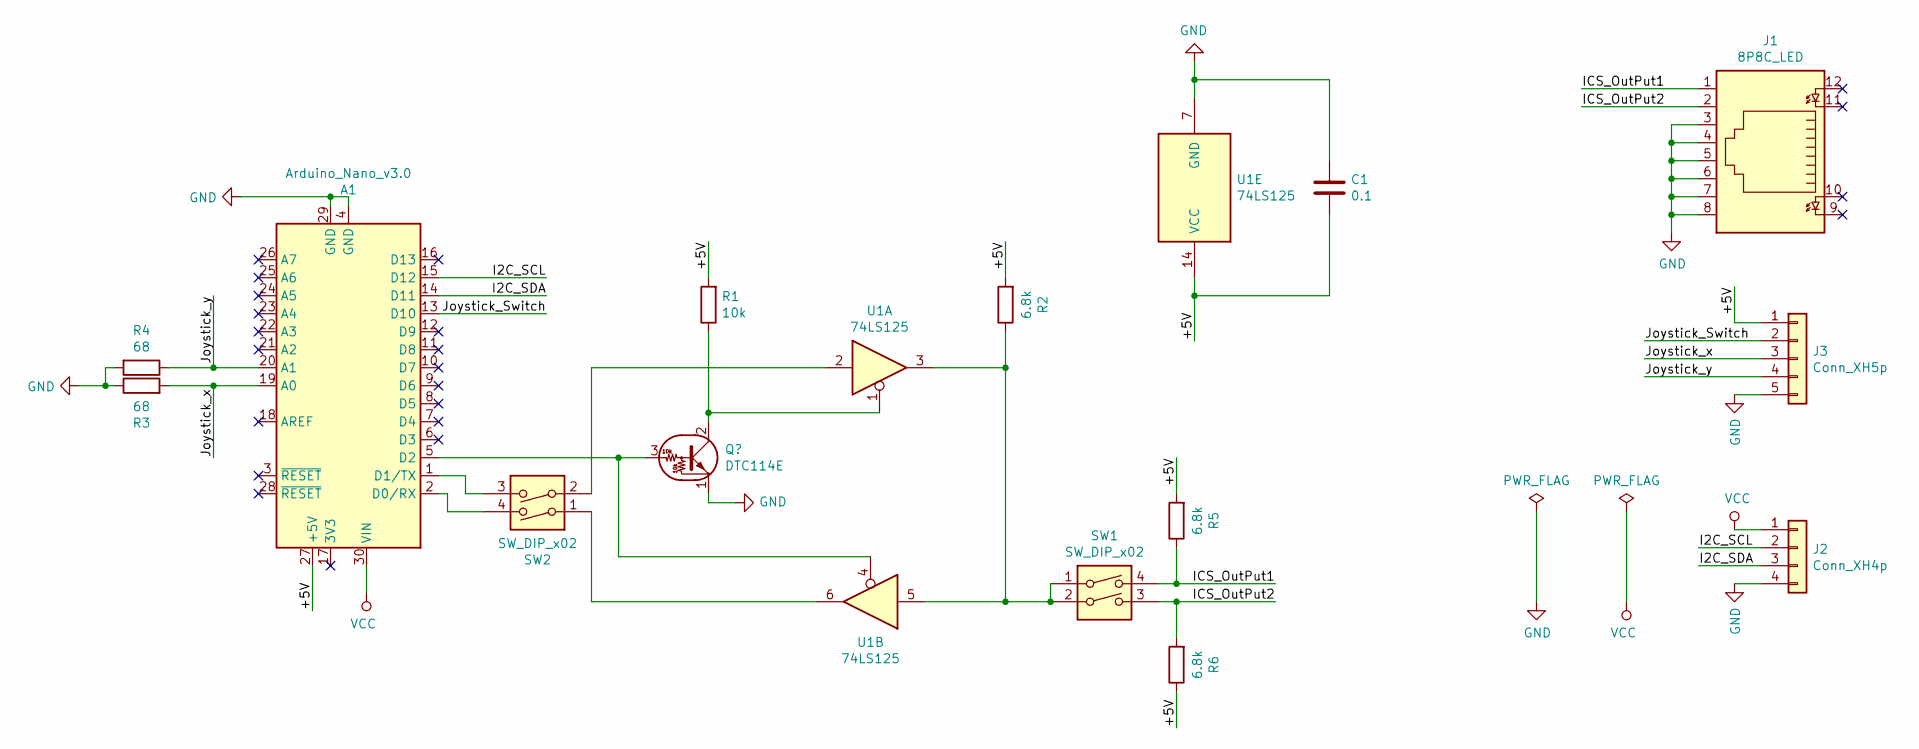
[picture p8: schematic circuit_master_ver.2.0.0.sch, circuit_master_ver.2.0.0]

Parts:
A1: Arduino_Nano_v3.0; Arduino_Nano
C1: 0.1; C_Disc_D4.7mm_W2.5mm_P5.00mm
J1: 8P8C_LED; RJ45_Cetus_J1B1211CCD_Horizontal
J2: Conn_XH4p; JST_XH_B4B-XH-A_1x04_P2.50mm_Vertical
J3: Conn_XH5p; JST_XH_B5B-XH-A_1x05_P2.50mm_Vertical
R1: 10k; R_Axial_DIN0207_L6.3mm_D2.5mm_P10.16mm_Horizontal
R2, R5, R6: 6.8k; R_Axial_DIN0207_L6.3mm_D2.5mm_P10.16mm_Horizontal
R3, R4: 68; R_Axial_DIN0207_L6.3mm_D2.5mm_P10.16mm_Horizontal
SW1, SW2: SW_DIP_x02; SW_DIP_SPSTx02_Slide_9.78x7.26mm_W7.62mm_P2.54mm
U1: 74LS125; DIP-14_W7.62mm_Socket_LongPads

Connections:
/+5V: A1.27 (+5V), C1.2, J3.1, R1.2, R2.2, R5.2, R6.1, U1.14 (VCC)
/I2C_SCL: A1.15 (D12), J2.2
/I2C_SDA: A1.14 (D11), J2.3
/ICS_OutPut1: J1.1, R5.1, SW1.4
/ICS_OutPut2: J1.2, R6.2, SW1.3
/Joystick_Switch: A1.13 (D10), J3.2
/Joystick_x: A1.19 (A0), J3.3, R3.2
/Joystick_y: A1.20 (A1), J3.4, R4.1
GND: A1.4 (GND), A1.29 (GND), C1.1, J1.3, J1.4, J1.5, J1.6, J1.7, J1.8, J2.4, J3.5, R3.1, R4.2, U1.7 (GND); also elsewhere on the board
unnamed: A1.1 (D1/TX), SW2.3
unnamed: A1.2 (D0/RX), SW2.4
unnamed 11: A1.5 (D2), U1.4; also elsewhere on the board
unnamed 12: R1.1, U1.1; also elsewhere on the board
unnamed: R2.1, SW1.1, SW1.2, U1.3, U1.5
unnamed: SW2.1, U1.6
unnamed: SW2.2, U1.2
VCC: A1.30 (VIN), J2.1

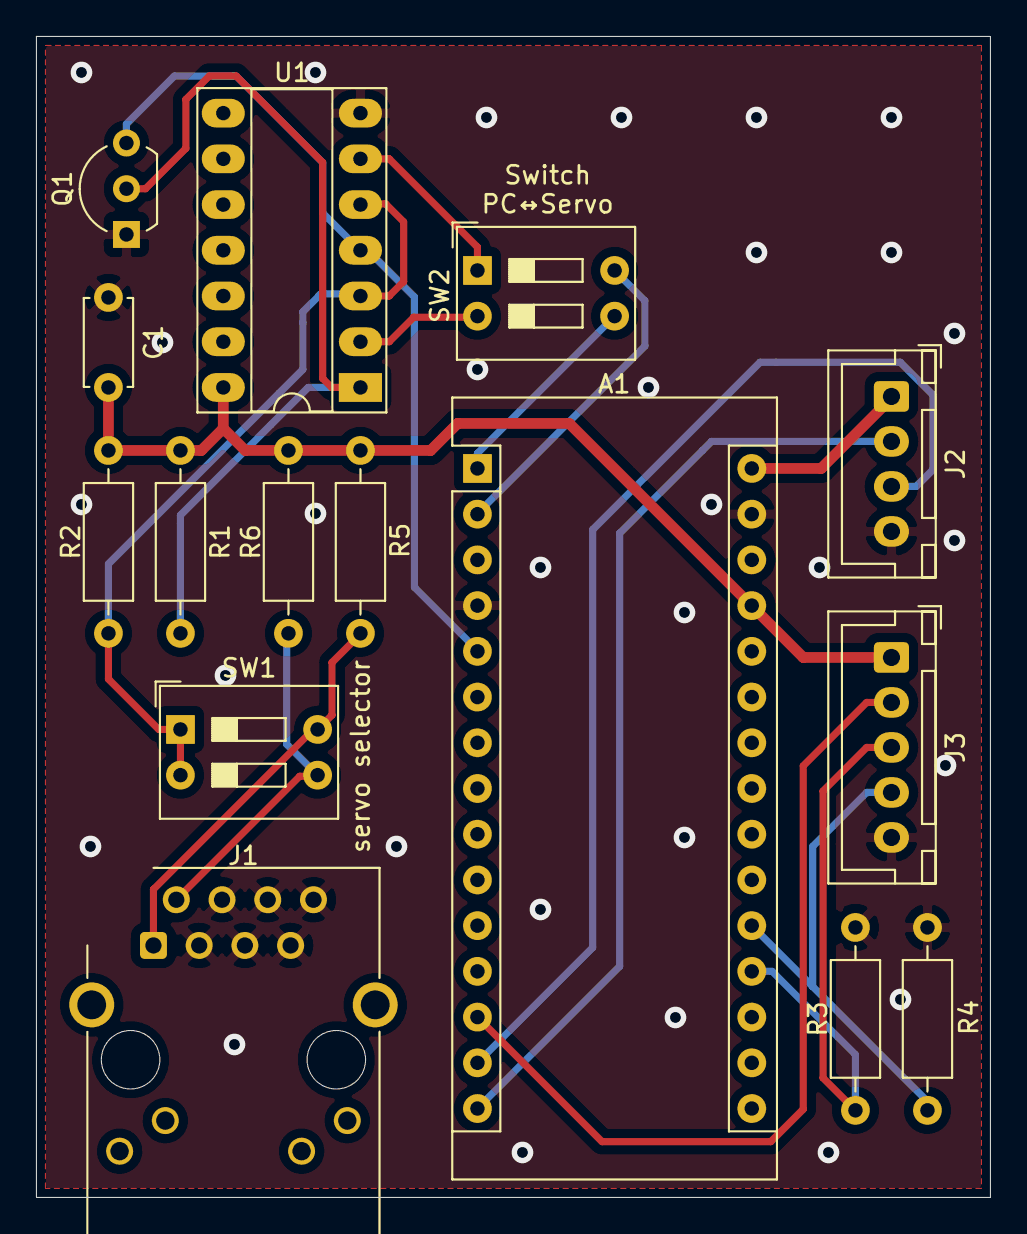
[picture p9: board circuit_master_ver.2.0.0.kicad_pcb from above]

Board: 2 copper layers, 53.0 x 64.5 mm, 15 parts (0 on the bottom side), 17 nets.

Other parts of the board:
Q1: DTC114EL; TO-92L_Inline_Wide

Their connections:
GND: Q1.1; also elsewhere on the board
unnamed 11: Q1.3; also elsewhere on the board
unnamed 12: Q1.2; also elsewhere on the board

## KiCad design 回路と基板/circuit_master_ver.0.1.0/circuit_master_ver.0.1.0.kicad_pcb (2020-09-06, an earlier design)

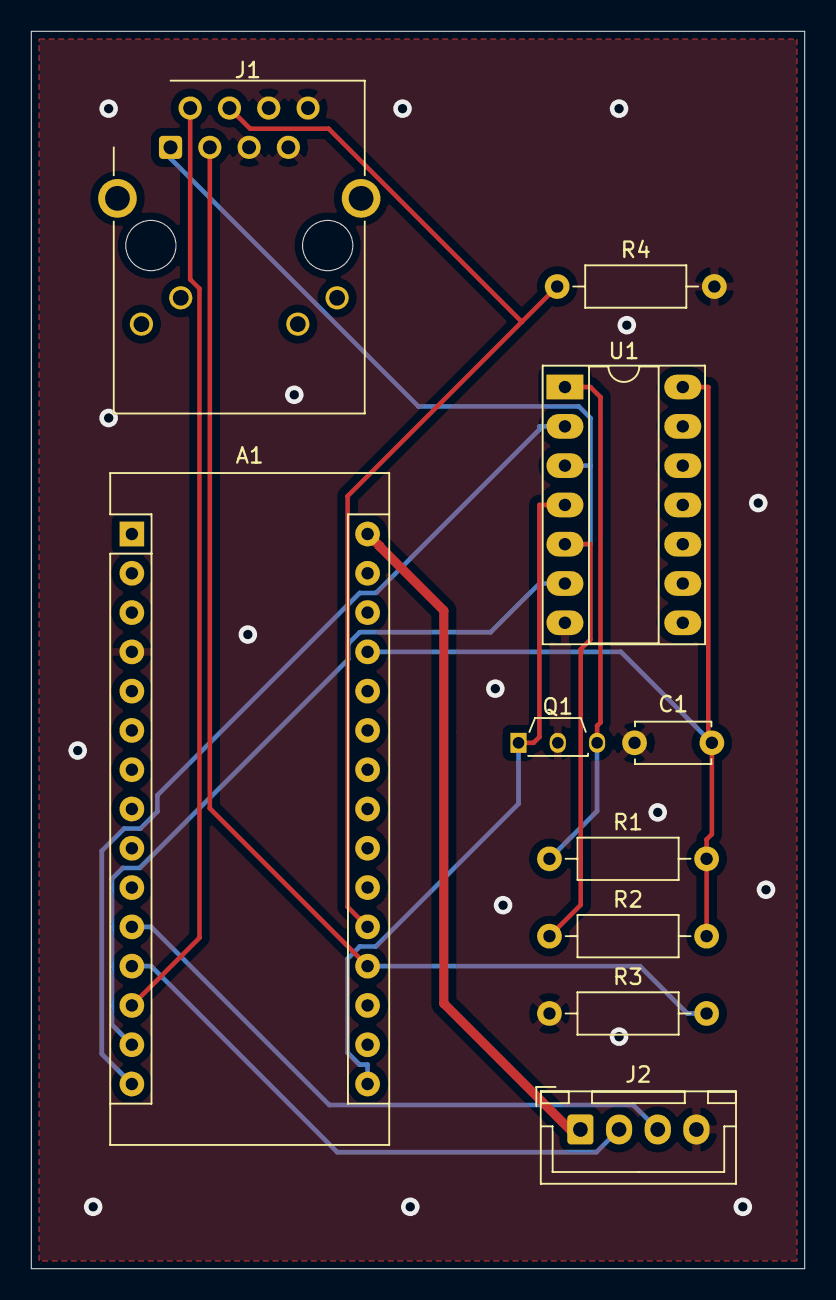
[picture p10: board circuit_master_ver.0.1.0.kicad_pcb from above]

Board: 2 copper layers, 50.0 x 80.0 mm, 10 parts (0 on the bottom side), 13 nets.

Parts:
A1: Arduino_Nano_v3.0; Arduino_Nano
C1: 0.1; C_Disc_D4.7mm_W2.5mm_P5.00mm
J1: 8P8C_LED; RJ45_Cetus_J1B1211CCD_Horizontal
J2: Conn_XH4p; JST_XH_B4B-XH-A_1x04_P2.50mm_Vertical
Q1: DTC114EL; TO-92S_Wide
R1: 10k; R_Axial_DIN0207_L6.3mm_D2.5mm_P10.16mm_Horizontal
R2: 2.2k; R_Axial_DIN0207_L6.3mm_D2.5mm_P10.16mm_Horizontal
R3, R4: 68; R_Axial_DIN0207_L6.3mm_D2.5mm_P10.16mm_Horizontal
U1: 74LS125; DIP-14_W7.62mm_Socket_LongPads

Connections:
/+5V: A1.27, C1.2, R1.2, R2.2, U1.14
/I2C_SCL: A1.12, J2.2
/I2C_SDA: A1.11, J2.3
/ICS_OutPut: J1.1, R2.1, U1.3, U1.5
/Joystick_Switch: A1.13, J1.2
/Joystick_x: A1.19, J1.3, R3.2
/Joystick_y: A1.20, J1.4, R4.1
GND: A1.4, A1.29, C1.1, J1.5, J1.6, J1.7, J1.8, J2.4, Q1.2, R3.1, R4.2, U1.7
unnamed: A1.14, U1.6
unnamed: A1.15, U1.2
unnamed: A1.16, Q1.1, U1.4
unnamed: Q1.3, R1.1, U1.1
VCC: A1.30, J2.1

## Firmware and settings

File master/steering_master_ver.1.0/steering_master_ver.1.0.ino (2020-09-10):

///
/// mainファイル
///
/****************************************************
 * マクロ部
 ****************************************************/
#include "subs_ver.1.0.h"

/****************************************************
 * グローバル変数/配列 宣言部
 ****************************************************/
// EEPEOMに保存されるパラメータの初期値。
int max_angle = 135;	//舵角の最大値(0 ~ 135)
int stretch = 64;	//サーボモータのストレッチ(1~127)
int speed = 64;		//サーボモータのスピード(1~127)
int centerPS_x = 100;	//サーボモータのx軸の中央値(0~200)
int centerPS_y = 100;	//サーボモータのy軸の中央値(0~200)
// アナログスティックの押し込みで設定する中央値の初期値
int tmp_centerPS_x = 512;	//一時的なスティックx軸の中央値(0~1023)
int tmp_centerPS_y = 512;	//一時的なスティックy軸の中央値(0~1023)

// スティックの押し込み判定用の変数群
int var0 = 0;
int old_var0 = 0;
int state0 = 0;

// デバッグモード移行判定用の変数群
int enable_debug = 0;
int var1 = 0;
int old_var1 = 0;
int state1 = 0;

/****************************************************
 * Arduino 要求関数部
 ****************************************************/
void setup() {
	//各昨日のセットアップ
	init_stick();
	init_cmd();
	init_servo();
	init_memory();

	//メイン処理部に関するセットアップ
	pinMode(PIN_SW1, INPUT_PULLUP);	//パラメータロードスイッチ
	pinMode(PIN_SW2, INPUT_PULLUP);	//デバッグモード移行用スイッチ
	pinMode(PIN_LED1, OUTPUT);
	pinMode(PIN_LED2, OUTPUT);
	digitalWrite(PIN_LED1, HIGH);	//電源投入のインジケーター
	digitalWrite(PIN_LED2, LOW);	//デバッグモード用インジケーター
}

//動作時、基本的には以下の関数のみでループします。
void loop() {
	move_servo();
	switch_debug();		//デバッグモード移行判定
	update_center();	//スティックの押し込み判定
	//enable_debug = 1のとき、デバッグモード.
	switch (enable_debug) {
		case 1:
			judge_load();
			break;
		default:
			break;
	}
}

/****************************************************
 * 独自関数部
 ****************************************************/
// 提言：以下の関数は別ファイルに移すかどうかで悩んでやめました。移したほうが分かりやすければそうしてください。

// スティックの中央値判定
// スティックの押し込みスイッチが押された場合、その時のスティックの値を中央値に設定する。
// 提言：この機能は使いにくいため、場合によってはスイッチの割り当てを変更したり、機能の無効化をしてください。
void update_center() {
	analog_stick tmp_state = stick_state();
	var0 = tmp_state.sw;

	//押された瞬間の読み取り
	if (var0 == HIGH && old_var0 == LOW) {
		state0 = 1 - state0;
		delay(10);	//チャタリング防止
	}
	//離された瞬間の読み取り
	if (var0 == LOW && old_var0 == HIGH) {
		delay(10);	//チャタリング防止
	}

	old_var0 = var0;

	if (state0 == 1) {	//スティックが押されたときの処理
		// 押されたときのスティックの傾きを保存
		tmp_centerPS_x = tmp_state.x;
		tmp_centerPS_y = tmp_state.y;
		// スティックが押されてから、スティックが中央に戻るか、1sec経つまでは他の処理をさせない。
		for (int i = 0; i < 1000; i++) {
			analog_stick now_state = stick_state();
			//中央に戻ったらループ解除。ただし、中央値は度々変化するので注意。
			// 現状、中央に戻ってのループ解除は実質機能していない。512の値を適宜調節してください。
			if (now_state.x == 512 && now_state.y == 512) {	//中央に戻ったらループ解除
				break;
			}
			delay(1);
		}
		state0 = 0;
	}
}


// デバッグモード移行判定
// デバッグモード移行スイッチが押された場合、デバッグモードとコマンドラインを有効化する。
void switch_debug() {
	var1 = digitalRead(PIN_SW2) ? 0 : 1;

	// 押された瞬間の読み取り
	if(var1 == HIGH && old_var1 == LOW) {
		state1 = 1 - state1;
		delay(10);	//チャタリング防止
	}
	// 離された瞬間の読み取り
	if(var1 == LOW && old_var1 == HIGH) { 
		delay(10);	//チャタリング防止
	}

	old_var1 = var1;

	if(state1 == 1) {
		digitalWrite(PIN_LED2, HIGH);
		enable_debug = 1;
		start_cmd();
	} else {
		digitalWrite(PIN_LED2, LOW);
		enable_debug = 0;
		stop_cmd();
	}
}

// パラメータロードの判定
// デバッグモード時にパラメータロードスイッチが1秒以上押された場合、パラメータロードを行う。
void judge_load() {
	int tmp_var;
	if (enable_debug == 0) {
		return;
	}
	for (int i = 0; i < 100; i++) {
		tmp_var = digitalRead(PIN_SW1) ? 0 : 1;
		if (tmp_var == LOW) {
			return;
		}
		delay(10);
	}
	void load_parameters();

	// パラメータロード完了できたかの確認用にLEDを点滅
	digitalWrite(PIN_LED2, LOW);
	delay(200);
	digitalWrite(PIN_LED2, HIGH);
	delay(200);
	digitalWrite(PIN_LED2, LOW);
	delay(200);
	digitalWrite(PIN_LED2, HIGH);
	delay(200);
	digitalWrite(PIN_LED2, LOW);
	delay(200);
	digitalWrite(PIN_LED2, HIGH);
}

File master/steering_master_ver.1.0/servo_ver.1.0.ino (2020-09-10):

///
/// サーボ駆動に関するファイル
///
/****************************************************
 * マクロ部
 ****************************************************/
#include "subs_ver.1.0.h"

/****************************************************
 * グローバル変数/配列 宣言部
 ****************************************************/
int posData;

//コマンドの定義
const byte ICS_POS_CMD = 0x80;
const byte ICS_PARA_WRITE_COMMND =0xC0;
const byte SUB_ST_COMMND = 0x01;
const byte SUB_SP_COMMND = 0x02;
const byte ICS_SET_ID_COMMND = 0xE0;
const byte SUB_ICS_SET_ID_COMMND = 0x01;

/****************************************************
 * 独自関数部
 ****************************************************/
// サーボモータ関連の初期設定
void init_servo() {
	Serial.begin(115200, SERIAL_8E1);	//UARTの通信設定
	pinMode(PIN_EN, OUTPUT);			//送受信切替ピンの設定
	digitalWrite(PIN_EN, LOW);			//常に受信モードにしておく
}


// サーボモータを駆動する
void move_servo() {
	analog_stick now_state = stick_state();	//スティックの情報を取得
	int send_PS_x = calc_angle(now_state.x, centerPS_x, tmp_centerPS_x);
	int send_PS_y = calc_angle(now_state.y, centerPS_y, tmp_centerPS_y);
	posData = ics_set_pos(0, send_PS_x);
	posData = ics_set_pos(1, send_PS_y);
}


// スティックのアナログ値、尾翼の最大動作角度、中央値からサーボへ送る値を算出
int calc_angle(int analog_num, int centerPS, int tmp_centerPS) {
	// 以下の計算は型によっては溢れたりするので、注意してください。
	float Max_amp = 4000 * (max_angle / 135);
	long max_amp = Max_amp;
	long send_centPS = (centerPS - 100) * 40 + 7500;
	long amp = ((analog_num + tmp_centerPS - 1024) * max_amp) / 512;
	long send_PS = send_centPS + amp;
	if (send_PS > 7500 + max_amp) {
		send_PS = 7500 + max_amp;
	}
	if (send_PS < 7500 - max_amp) {
		send_PS = 7500 - max_amp;
	}
	/*デバッグ用
	cmdSerial.print("analog_num : "); cmdSerial.println(analog_num);
	cmdSerial.print("max_amp : "); cmdSerial.println(max_amp);
	cmdSerial.print("send_centPS : "); cmdSerial.println(send_centPS);
	cmdSerial.print("amp : "); cmdSerial.println(amp);
	cmdSerial.print("send_PS : "); cmdSerial.println(send_PS);
	cmdSerial.println("------------");
	*/
	return (int)send_PS;
}


// 送受信する
bool Synchronize(byte *txBuff, size_t txLength, byte *rxBuff, size_t rxLength) {
	int size;	//受信したbyte数

	//定義していなかったらエラーにする
	if(Serial == false) {
		return false;
	}

	Serial.flush();

	digitalWrite(PIN_EN, HIGH);

	Serial.write(txBuff, txLength);

	Serial.flush(); //送信が終わるのを待つ

	digitalWrite(PIN_EN, LOW);

	size = Serial.readBytes(rxBuff, rxLength);

	if(size != rxLength) {  //指定した受信数かどうか確認
		return false;
	}
	return true;
}


// ポジションコマンドを送る
int ics_set_pos(byte id, unsigned short pos) {
	byte tx_data[3];
	byte rx_data[3];
	bool flag;
	int rAngle; //受信した角度データ
	/// 送信コマンドを作成
	tx_data[0] = ICS_POS_CMD + id;
	tx_data[1] = (byte)((pos & 0x3F80) >> 7);
	tx_data[2] = (byte)(pos & 0x007F);

	//送受信を行う
	flag = Synchronize(tx_data, 3, rx_data, 3);

	if(flag == false) { //失敗した場合は-1を返す
		return -1;
	}

	rAngle = ((rx_data[1] << 7) & 0x3F80) + (rx_data[2] & 0x007F);

	return rAngle;
}


// ストレッチを変更する
bool ics_set_st(byte id, byte stData) {
	byte tx_data[3];
	byte rx_data[3];
	bool flag;
	/// 送信コマンドを作成
	tx_data[0] = ICS_PARA_WRITE_COMMND + id;
	tx_data[1] = SUB_ST_COMMND;
	tx_data[2] = stData;

	//送受信を行う
	flag = Synchronize(tx_data, 3, rx_data, 3);

	if(flag == false) { //失敗した場合は-1を返す
		return -1;
	}

	return flag;
}


// スピードを変更する
bool ics_set_sp(byte id, byte spData) {
	byte tx_data[3];
	byte rx_data[3];
	bool flag;
	/// 送信コマンドを作成
	tx_data[0] = ICS_PARA_WRITE_COMMND + id;
	tx_data[1] = SUB_SP_COMMND;
	tx_data[2] = spData;

	//送受信を行う
	flag = Synchronize(tx_data, 3, rx_data, 3);

	if(flag == false) { //失敗した場合は-1を返す
		return -1;
	}

	return flag;
}


// ID書き込み
bool ics_set_id(byte idData) {
	byte tx_data[4];
	byte rx_data[1];
	bool flag;
	/// 送信コマンドを作成
	tx_data[0] = ICS_SET_ID_COMMND + idData;
	tx_data[1] = SUB_ICS_SET_ID_COMMND;
	tx_data[2] = SUB_ICS_SET_ID_COMMND;
	tx_data[3] = SUB_ICS_SET_ID_COMMND;

	//送受信を行う
	flag = Synchronize(tx_data, 4, rx_data, 1);

	if(flag == false) {	//失敗した場合は-1を返す
		return -1;
	}

	return flag;
}

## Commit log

2020-09-06 upload befor we create
    [circuit_master_ver.0.1.0-B_Cu.gbl, circuit_master_ver.0.1.0-B_Mask.gbs, circuit_master_ver.0.1.0-B_Paste.gbp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]
2020-09-06 softwareSerialの動作テスト実行
2020-09-08 SoftwareSerialを用いたコマンドラインの作成完了
2020-09-08 とりあえずスティックで動いてデバッグモードも動作できるver.0.2を作成しました。
2020-09-08 誤字訂正
2020-09-09 ver1.0作成開始
2020-09-10 アナログスティックの入力などから、サーボモータへ送信する値の算出計算の完成
2020-09-10 操舵のソースコード。及び引き継ぎ出力
2020-09-13 資料更新
